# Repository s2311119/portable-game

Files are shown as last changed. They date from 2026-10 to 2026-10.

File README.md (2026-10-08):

# portable-game
```text
① 明らかなバグだけ直す
Skill初期化、ドロップ、item ID、経験値進化、最低ダメージなど。
以下
・Skill::dependence/category
・戦闘ドロップ処理
・ボス・特殊敵のアイテムID
・複数レベルアップ時の進化
・最低ダメージ/回復
② 進化システムを整理する
5系統をどう分岐させたいかを先に決めてからテーブルを書き直す。
③ ゲームバランスを数値で見る
各Lvの味方ステータス、敵ステータス、与ダメージ、必要戦闘回数などを表にして調整する。
④ 最後にリファクタリング
大量に残っている昔のコメントアウトコードを削除し、9,000行の .ino を少し整理する。
```

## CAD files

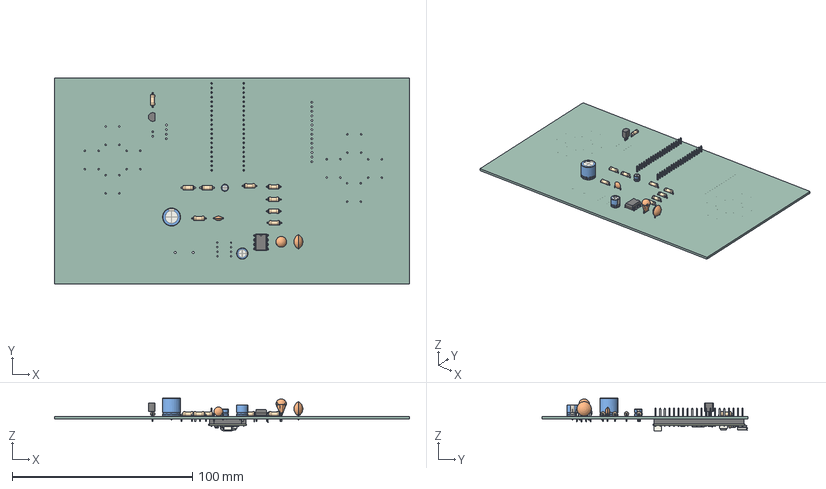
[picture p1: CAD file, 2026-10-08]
Circuit/gameki_kairo/gameki_kairo.step
197.0 x 114.5 x 18.1 mm
CP_Radial_D10.0mm_P7.50mm
R_Axial_DIN0207_L6.3mm_D2.5mm_P7.62mm_Horizontal x 9
DIP-8_W7.62mm
CP_Radial_Tantal_D6.0mm_P5.00mm
CP_Radial_D6.3mm_P2.50mm
TO-92_Inline
C_Disc_D8.0mm_W5.0mm_P5.00mm
C_Disc_D5.0mm_W2.5mm_P5.00mm
CP_Radial_D4.0mm_P2.00mm
RaspberryPi_Pico_H_Module_KiCad
RaspberryPi_Pico_Header_DIP-40_H2.54mm_KiCad
gameki_kairo_PCB

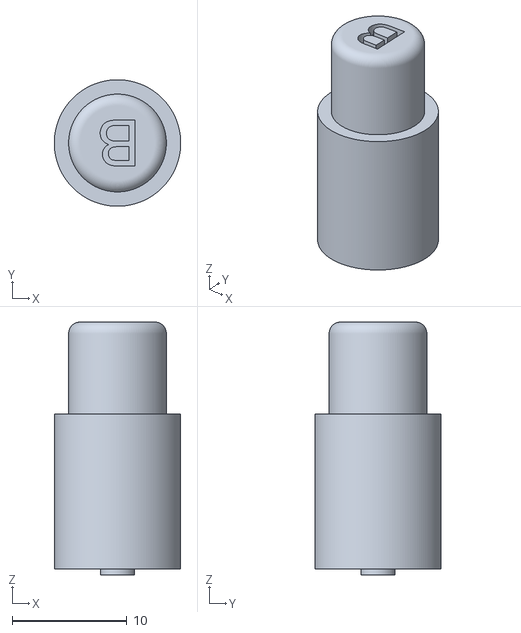
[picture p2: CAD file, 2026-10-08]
Fusion3Ddata/B_button.stl
11.0 x 11.0 x 22.0

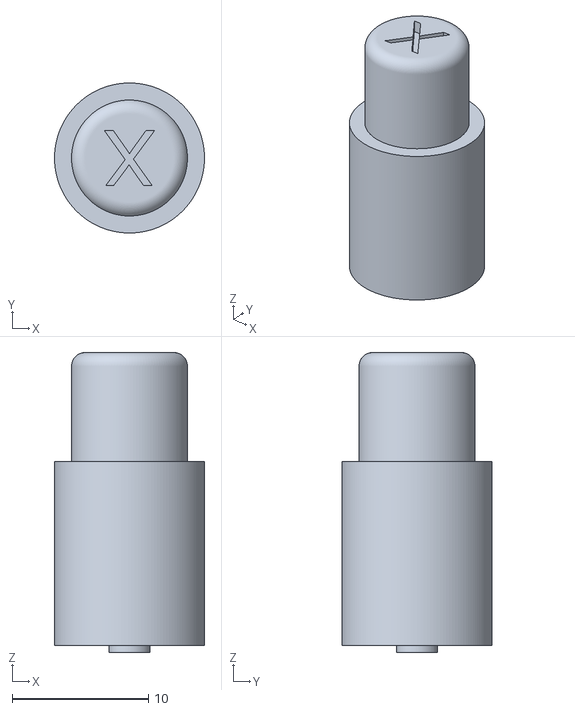
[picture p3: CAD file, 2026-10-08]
Fusion3Ddata/X_button.stl
11.0 x 11.0 x 22.0

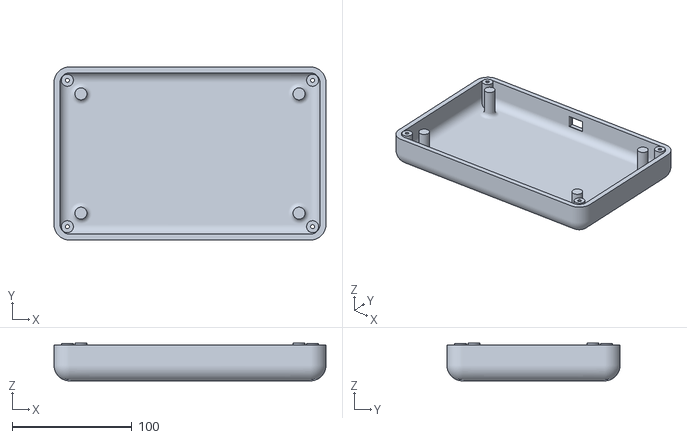
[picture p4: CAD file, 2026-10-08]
Fusion3Ddata/bottom_case.stl
227.0 x 144.5 x 31.5

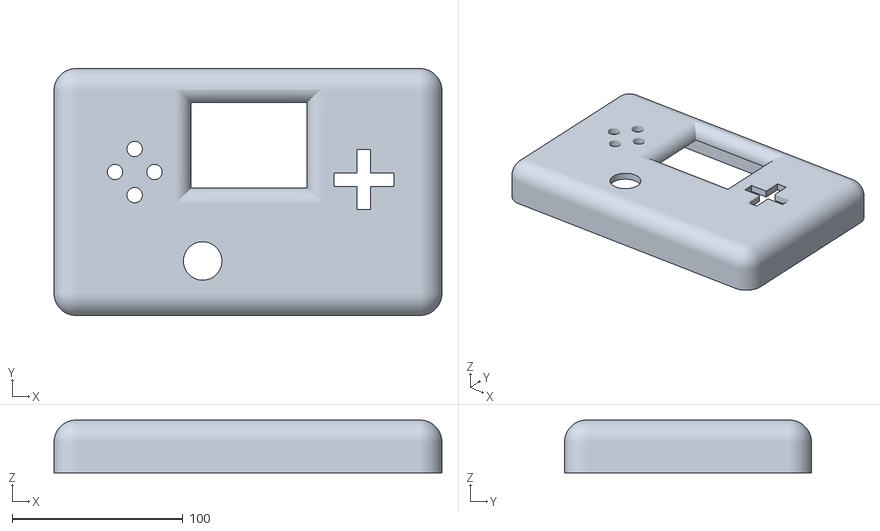
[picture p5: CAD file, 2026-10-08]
Fusion3Ddata/top_case.stl
227.0 x 144.5 x 31.0

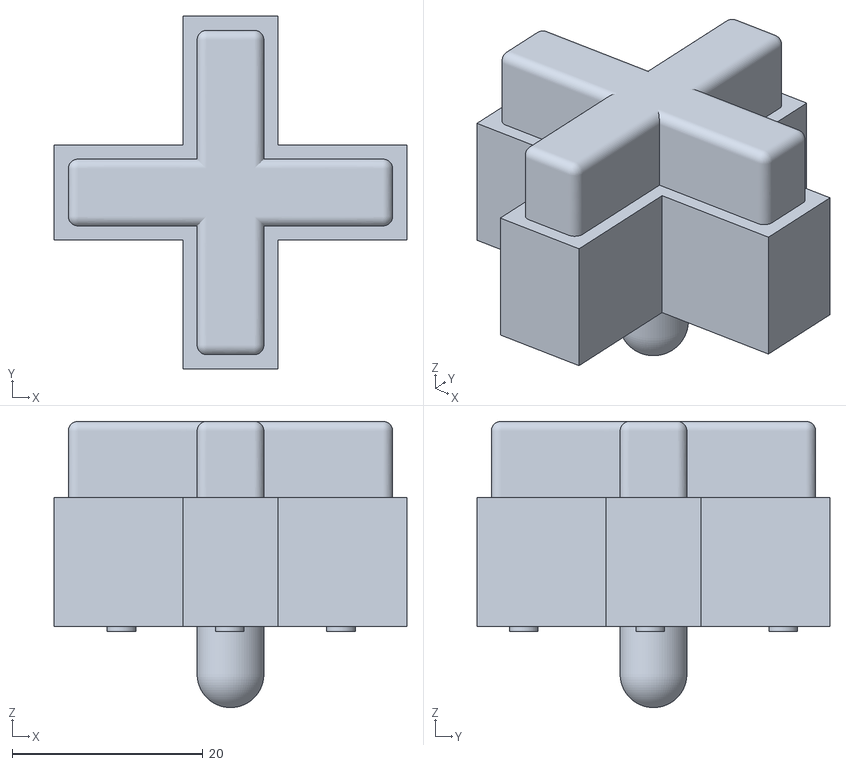
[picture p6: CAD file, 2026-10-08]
Fusion3Ddata/Cross_button.stl
37.0 x 37.0 x 30.0

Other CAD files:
Fusion3Ddata/A_button.stl
Fusion3Ddata/Y_button.stl

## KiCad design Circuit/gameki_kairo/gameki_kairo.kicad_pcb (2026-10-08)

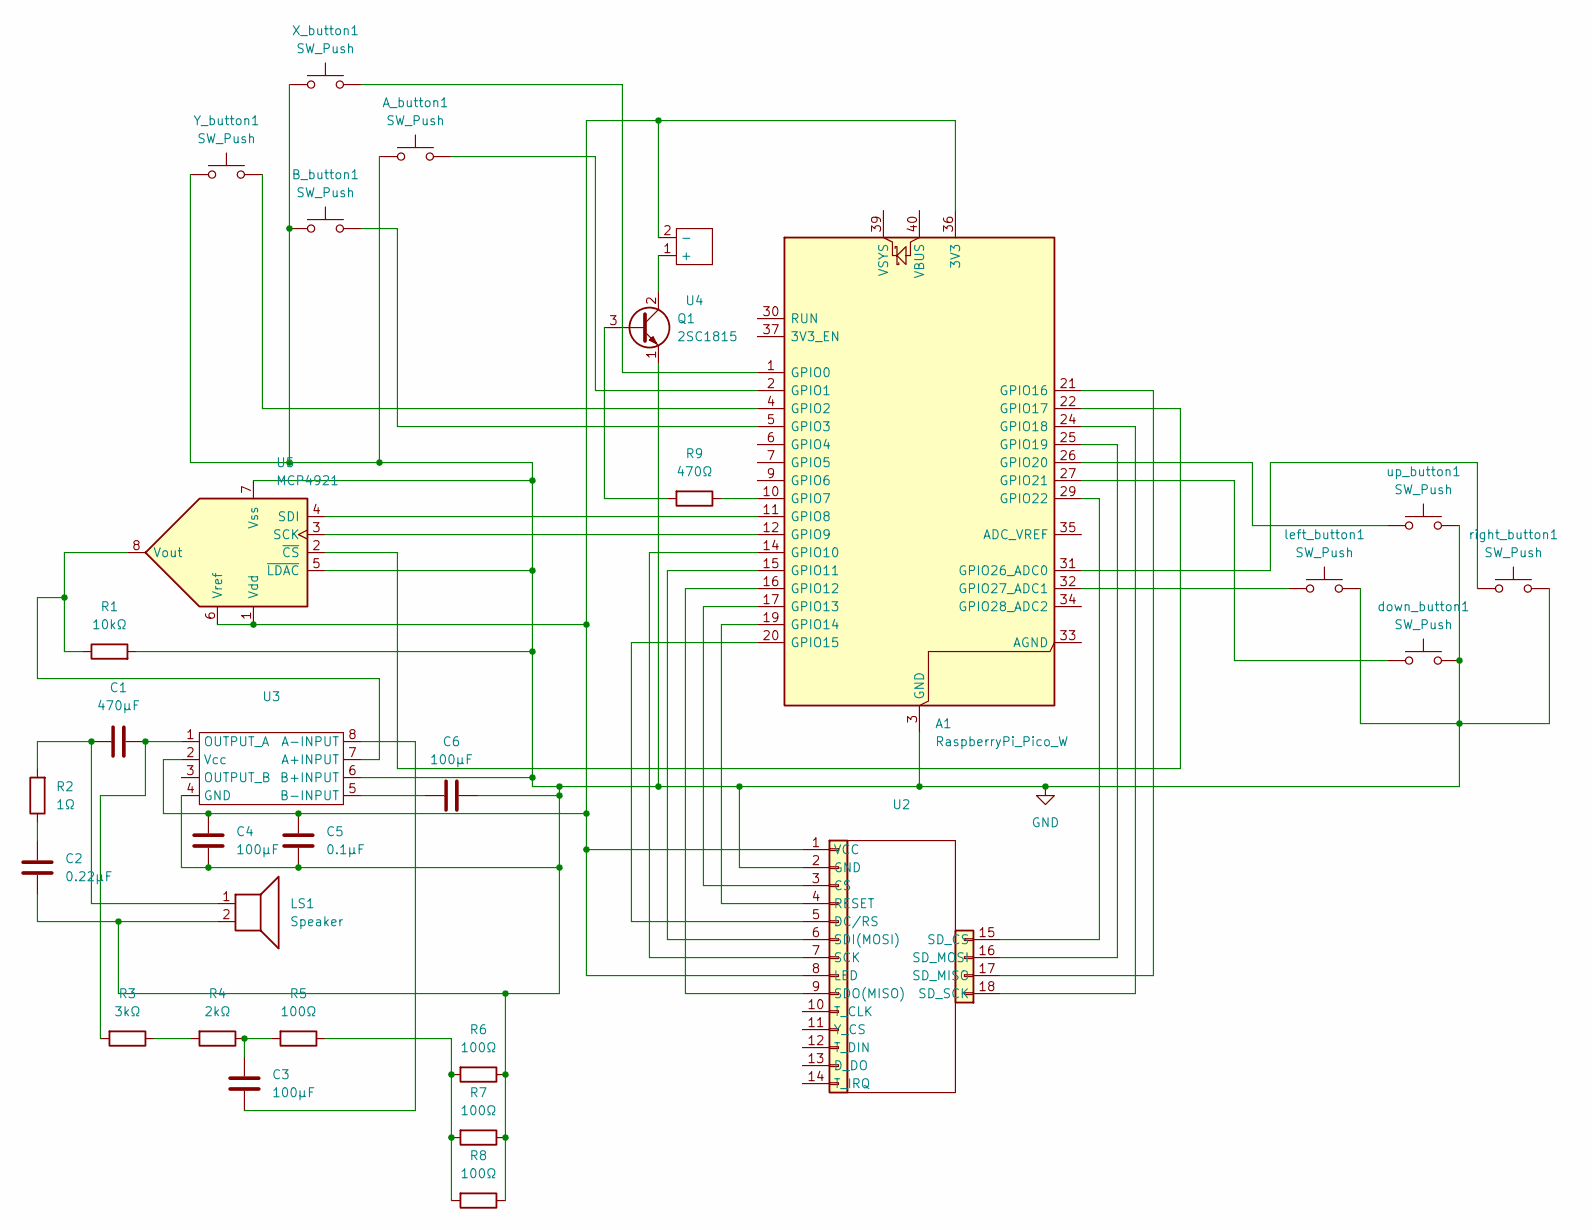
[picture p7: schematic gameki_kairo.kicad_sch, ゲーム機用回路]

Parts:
A1: RaspberryPi_Pico_W; RaspberryPi_Pico_Common_THT
A_button1: SW_Push; SW_MEC_5GTH9
B_button1: SW_Push; SW_MEC_5GTH9
C1: 470µF; CP_Radial_D10.0mm_P7.50mm
C2: 0.22µF; C_Disc_D5.0mm_W2.5mm_P5.00mm
C3: 100µF; CP_Radial_D4.0mm_P2.00mm
C4: 100µF; CP_Radial_Tantal_D6.0mm_P5.00mm
C5: 0.1µF; C_Disc_D8.0mm_W5.0mm_P5.00mm
C6: 100µF; CP_Radial_D6.3mm_P2.50mm
LS1: Speaker; Speaker_1
Q1: 2SC1815; TO-92_Inline
R1: 10kΩ; R_Axial_DIN0207_L6.3mm_D2.5mm_P7.62mm_Horizontal
R2: 1Ω; R_Axial_DIN0207_L6.3mm_D2.5mm_P7.62mm_Horizontal
R3: 3kΩ; R_Axial_DIN0207_L6.3mm_D2.5mm_P7.62mm_Horizontal
R4: 2kΩ; R_Axial_DIN0207_L6.3mm_D2.5mm_P7.62mm_Horizontal
R5, R6, R7, R8: 100Ω; R_Axial_DIN0207_L6.3mm_D2.5mm_P7.62mm_Horizontal
R9: 470Ω; R_Axial_DIN0207_L6.3mm_D2.5mm_P7.62mm_Horizontal
U2: MSP2807_1
U3: M2073_1_foot
U4: ブラシレス振動モーター
U5: MCP4921; DIP-8_W7.62mm
X_button1: SW_Push; SW_MEC_5GTH9
Y_button1: SW_Push; SW_MEC_5GTH9
down_button1: SW_Push; SW_MEC_5GTH9
left_button1: SW_Push; SW_MEC_5GTH9
right_button1: SW_Push; SW_MEC_5GTH9
up_button1: SW_Push; SW_MEC_5GTH9

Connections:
GND: A1.3 (GND), A1.8 (GND), A1.13 (GND), A1.18 (GND), A1.23 (GND), A1.28 (GND), A1.38 (GND), A_button1.1, B_button1.1, C2.1, C4.2, C5.1, C6.2, LS1.2, Q1.1 (E), R1.2, R6.1, R7.1, R8.1, U2.2 (GND), U3.4 (GND), U3.6 (B+INPUT), U5.5 (~LDAC), U5.7 (Vss), X_button1.1, Y_button1.1, down_button1.2, left_button1.2, right_button1.2, up_button1.2
unnamed: A1.36 (3V3), C4.1, C5.2, U2.1 (VCC), U2.8 (LED), U3.2 (Vcc), U4.2 (-), U5.1 (Vdd), U5.6 (Vref)
unnamed: A1.1 (GPIO0), X_button1.2
unnamed: A1.2 (GPIO1), A_button1.2
unnamed: A1.4 (GPIO2), Y_button1.2
unnamed: A1.5 (GPIO3), B_button1.2
unnamed: A1.10 (GPIO7), R9.1
unnamed: A1.11 (GPIO8), U5.4 (SDI)
unnamed: A1.12 (GPIO9), U5.3 (SCK)
unnamed: A1.14 (GPIO10), U2.7 (SCK)
unnamed: A1.15 (GPIO11), U2.6 (SDI(MOSI))
unnamed: A1.16 (GPIO12), U2.9 (SDO(MISO))
unnamed: A1.17 (GPIO13), U2.3 (CS)
unnamed: A1.19 (GPIO14), U2.4 (RESET)
unnamed: A1.20 (GPIO15), U2.5 (DC/RS)
unnamed: A1.21 (GPIO16), U2.17 (SD_MISO)
unnamed: A1.22 (GPIO17), U5.2 (~CS)
unnamed: A1.24 (GPIO18), U2.18 (SD_SCK)
unnamed: A1.25 (GPIO19), U2.16 (SD_MOSI)
unnamed: A1.26 (GPIO20), up_button1.1
unnamed: A1.27 (GPIO21), down_button1.1
unnamed: A1.29 (GPIO22), U2.15 (SD_CS)
unnamed: A1.31 (GPIO26_ADC0), right_button1.1
unnamed: A1.32 (GPIO27_ADC1), left_button1.1
unnamed: C1.1, LS1.1, R2.2
unnamed: C2.2, R2.1
unnamed: C3.2, R4.1, R5.2
unnamed: Q1.3 (B), R9.2
unnamed: Q1.2 (C), U4.1 (+)
unnamed: R3.1, R4.2
unnamed: R5.1, R6.2, R7.2, R8.2
unnamed: R1.1, U3.7 (A+INPUT), U5.8 (Vout)
unnamed: C3.1, U3.8 (A-INPUT)
unnamed: C6.1, U3.5 (B-INPUT)
unnamed: C1.2, R3.2, U3.1 (OUTPUT_A)

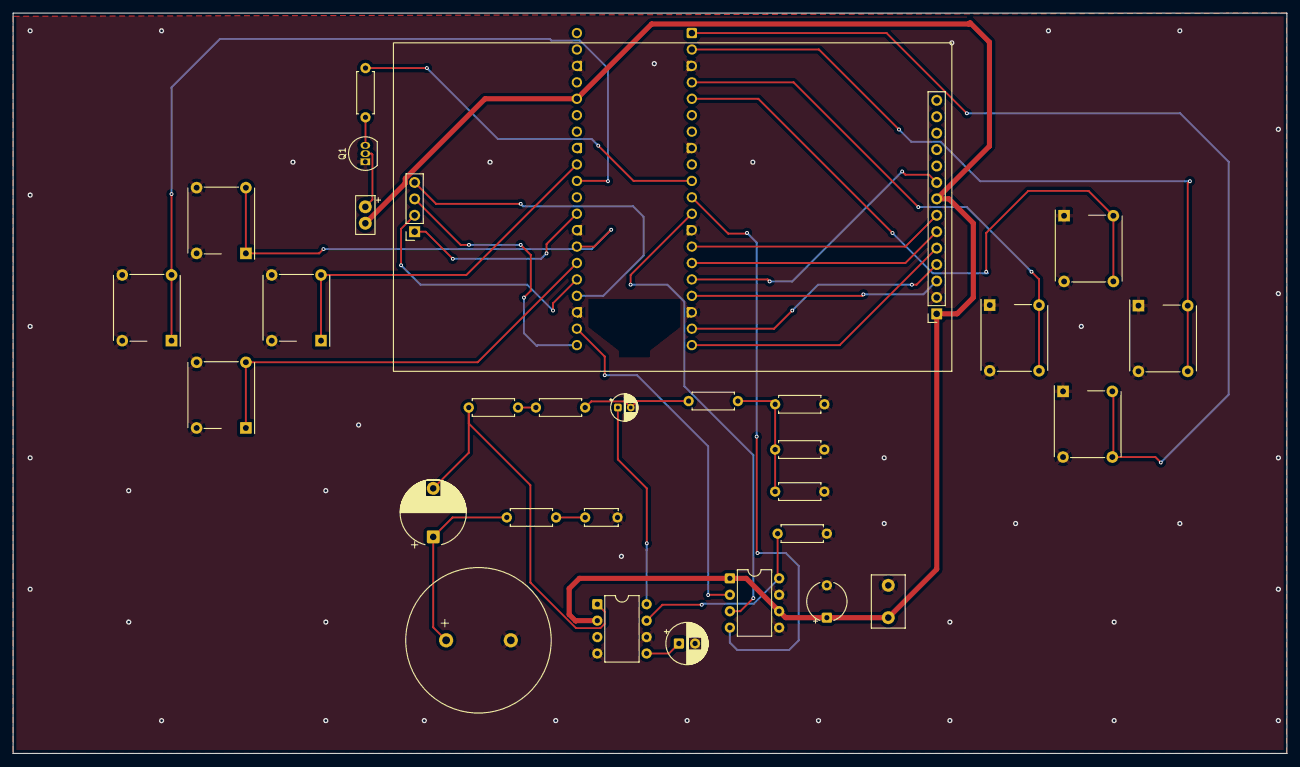
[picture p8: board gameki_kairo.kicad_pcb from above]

Board: 2 copper layers, 197.0 x 114.5 mm, 30 parts (1 on the bottom side), 35 nets.

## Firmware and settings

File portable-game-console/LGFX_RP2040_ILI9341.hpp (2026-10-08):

#pragma once

#define LGFX_USE_V1

#include <LovyanGFX.hpp>

// LGFX for Waveshare RP2040-LCD-0.96
// https://www.waveshare.com/wiki/RP2040-LCD-0.96

class LGFX : public lgfx::LGFX_Device
{
  lgfx::Panel_ILI9341 _panel_instance;
  lgfx::Bus_SPI       _bus_instance;
  lgfx::Light_PWM     _light_instance;

  public:
  LGFX(void)
  {
    {
      auto cfg = _bus_instance.config();
      cfg.spi_host   = 1;
      cfg.spi_mode   = 0;
      cfg.freq_write = 40000000; //もし通信速度が速すぎて動かない場合は10000000等に変更
      cfg.pin_sclk   = 10; //ボードの設計に合わせて変更。SPI通信のクロック信号のポート
      cfg.pin_miso   = -1; //今回の液晶にはMISO端子は不要なため、-1のままにする
      cfg.pin_mosi   = 11; //ボードの設計に合わせて変更。SPI通信のMOSI(TX)信号のポート
      cfg.pin_dc     = 15;  //ボードの設計に合わせて変更。DC通信のポート。
      _bus_instance.config(cfg);
      _panel_instance.setBus(&_bus_instance);
    }

    {
      auto cfg = _panel_instance.config();
      cfg.pin_cs       = 13; //ボードの設計に合わせて変更。CS信号のポート。
      cfg.pin_rst      = 14;//ボードの設計に合わせて変更。RST信号のポート。
      cfg.panel_width  = 240;//液晶の仕様に合わせて変更。ILI9341の場合240
      cfg.panel_height = 320;//液晶の仕様に合わせて変更。ILI9341の場合240<-多分320じゃね？
      cfg.offset_x     = 0;//液晶の仕様に合わせて変更。ここでは0
      cfg.offset_y     = 0;//液晶の仕様に合わせて変更。ここでは0
      cfg.invert       = false;//補色モードかどうか。trueだと、0xFFFFFFが黒になる
      cfg.rgb_order    = false;
      //cfg.offset_rotation = 0;
      _panel_instance.config(cfg);
    }

    {
      auto cfg = _light_instance.config();
      cfg.pin_bl      = 22;//ボードの設計に合わせて変更。バックライトLED制御をマイコンから行っていれば書く
      cfg.pwm_channel = 0;//1;//ボードの設計に合わせて変更。PWM channelは0か1になる。
      _light_instance.config(cfg);
      _panel_instance.setLight(&_light_instance);
    }

    setPanel(&_panel_instance);
  }
};

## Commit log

2026-10-10 Add action-ready stage before battle execution
2026-10-10 Persist current map state in saves
2026-10-10 Run audio timer on core1
2026-10-10 Avoid silent sample at audio buffer boundary
2026-10-10 Fix treasure chest material IDs
2026-10-10 Encapsulate current floor state
2026-10-12 Cache battle images in fixed ImageManager slots
2026-10-12 Extract SkillMenu selection and learning flow
2026-10-12 Make MenuFlow sole owner of menu screen selection
    Replace the public legacy MenuState with private MenuScreen and a read-only screen query. ShopMenu alone owns Choice/Buy/Sell; MenuFlow retains only SHOP, preserving one screen branch per frame and the existing input order.
2026-10-12 Return save requests from MenuFlow to top-level
    Perform the existing GameSession save before drawing the result in the same frame, then remove the obsolete component-argument SaveManager bridge. Save encoding and pause/sdLock sequence remain in th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
2026-10-12 Move equipment exchange transaction into EquipmentChangeSystem
    MenuFlow sends the selected slot and Inventory index after the existing SE. The system returns the old item, equips the new ID, then removes the selected stack in the same order.
2026-10-12 Move field drawing into WorldRenderer
    WorldRenderer owns the camera and previous-hero render cache because those values are specific to field drawing. Keep the existing tile selection, LCD calls and 32px line-sprite order while Graphic r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
2026-10-12 Route game BGM choices through semantic cues
    AudioManager maps the existing Town, Dungeon, battle, Title and Game Over cues to their unchanged track IDs and delegates to the existing switch code. Game-side callers retain their previous branch a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
2026-10-12 Move Storage method bodies out of its header
    Move the constructor, initialization, track-switch and refill implementations into Storage.cpp without changing their statements or call order. This pure implementation move precedes separate synchro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
2026-10-12 Move audio file handles into Storage
    Storage now owns the existing 100 FsFile slots and uses them at the same open, seek and read points. AudioManager continues to own playback buffers; initialization, switch and refill control flow rem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
2026-10-12 Move BGM track initialization into AudioManager
    AudioManager now owns the existing filename table and initial buffer setup. Storage performs the same SD begin, open, seek and reads through narrow operations, in the same setup order and with the un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
2026-10-12 Reduce Arduino sketch to Game entry points
